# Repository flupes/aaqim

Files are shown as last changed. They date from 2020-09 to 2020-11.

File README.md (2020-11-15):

# aaqim = Arduino AQI Monitor

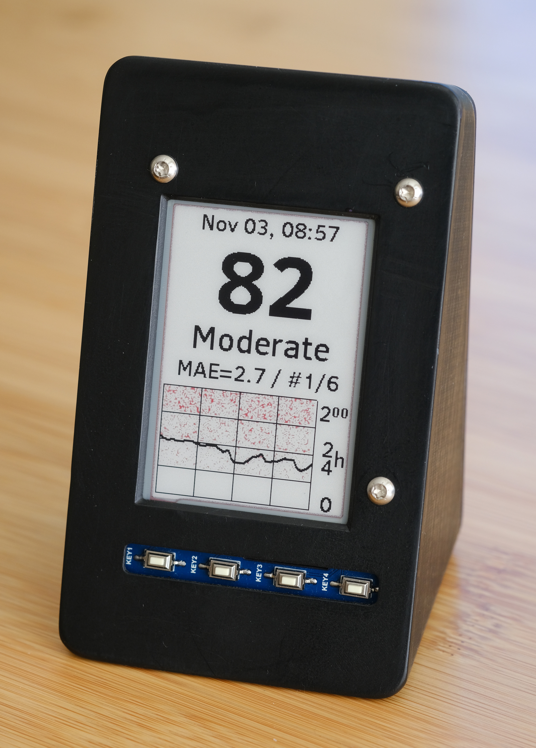
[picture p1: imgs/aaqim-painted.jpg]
AAQIM Monitor with Enclosure


Simple Air Quality Monitor using data collected from the **web** (no local sensor).

Based on an ESP8266 and E-paper display.

This is not a general, multi-purpose code base, but a quick hack for personal
use.

## Why

The air quality has been a real concern in the West from August 2020.
[Purple Air](https://www.purpleair.com/map) and
[Air Now](https://gispub.epa.gov/airnow/) maps are great tools to evaluate if
you can dare point your nose outside the confine of your shelter or not.
However, I wanted a solution that provides the current state of pollution in a
glimpse, without relying logging on a computer.

Ideally, you would setup your own sensor and create your DIY display to monitor
the pollution in real time. However, due to high demand, air quality sensors are
out of stock everywhere!

The next best option is then to use the data already available. There are more
than 15 Purple Air stations in a 500m diameter circle around my house, so it is
possible to get data localized enough to be relevant. The next requirement for
me was to create a low power solution: I would prefer to not contribute more to
the global warming just for my personal convinience. So a typical solution
relying on a Raspberry Pi single board computer is not considered here.

This project relies on micro-controller with WiFi capabilities to collect other
people sensor data. The display is based on a E-Paper panel that does not
consume current only when it needs to be updated. Since air quality is a slow
evolving parameter, the board and panel are simply stopped between updates,
leading to a very low power solution.

<p float="left">
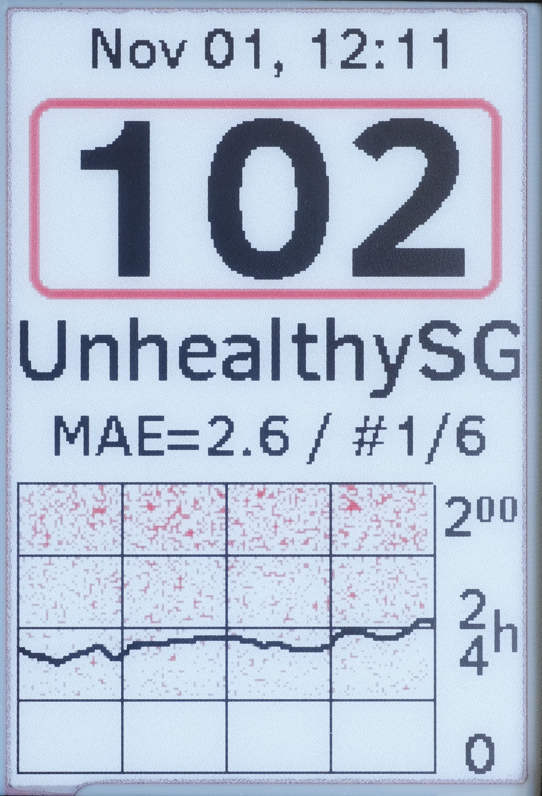
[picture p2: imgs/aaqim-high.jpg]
AAQIM Display Details
  
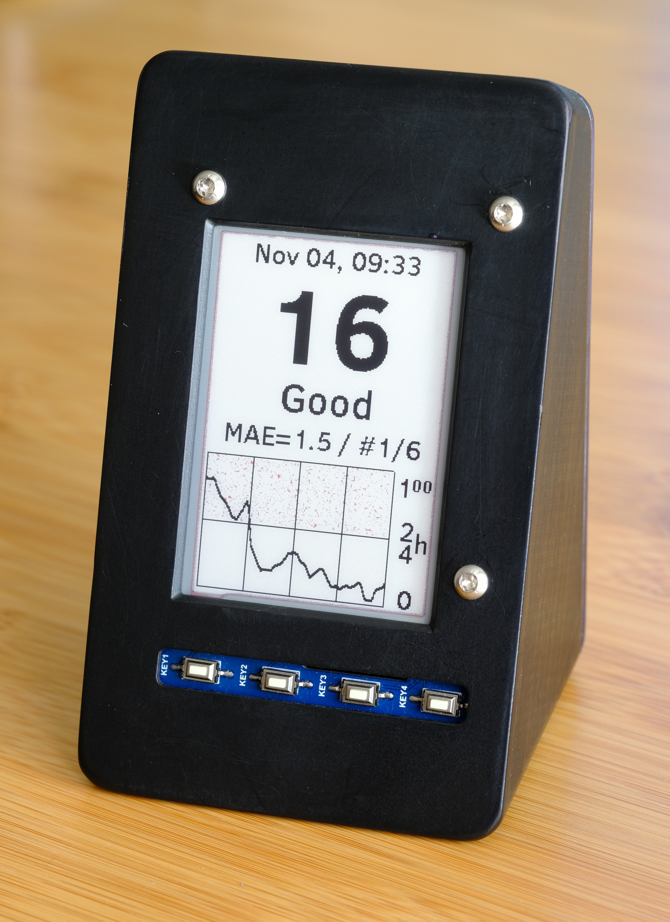
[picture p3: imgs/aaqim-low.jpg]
AAQIM Graph Display
  
</p>

## Details

  - [Some notes on the design](./design.md) (historical data and power consumption)
  - [Hardware related info](./hardware.md) (pinout, etc.)

The STL models for the enclosure are in the `./stls` directory.
The source Fusion-360 model is available with [this link](https://a360.co/31YtSna).
The enclosure holds the Huzzah in place without any screws.

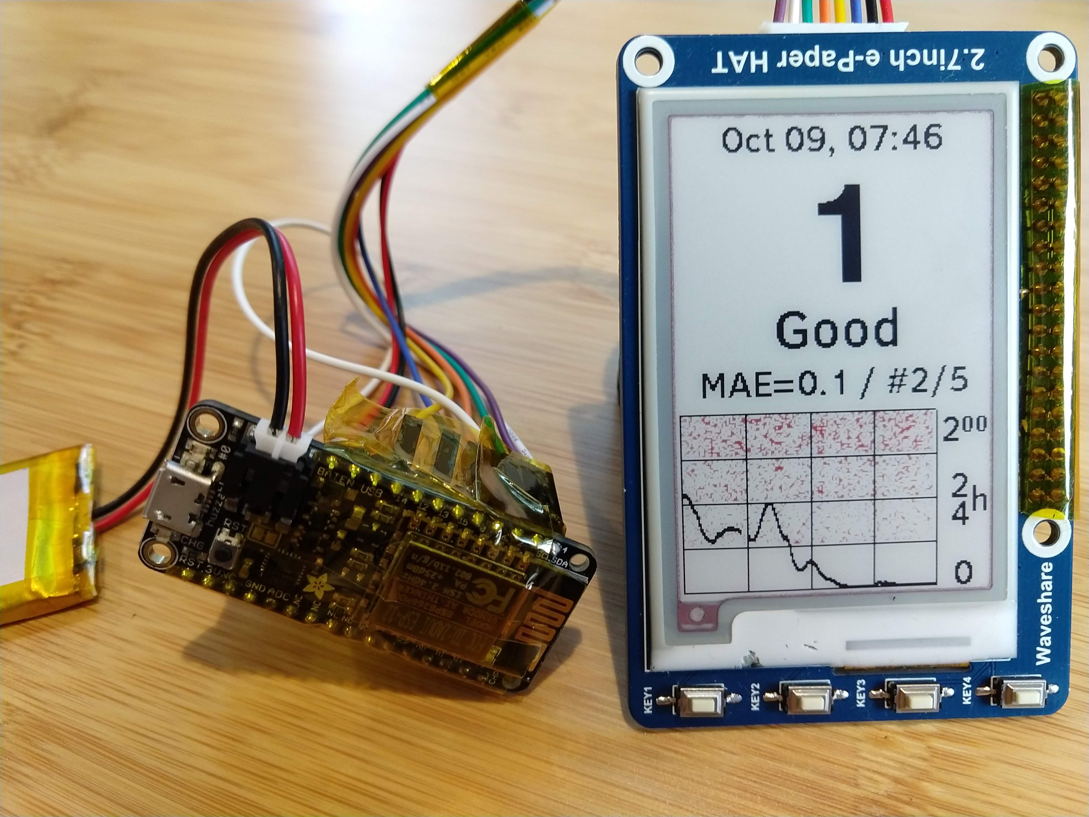
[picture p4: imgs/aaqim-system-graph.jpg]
AAQIM System


## Bill of Material

Not by design, just un-unsed parts from previous projects:
  - ESP8266 [Adafruit Huzzah](https://www.adafruit.com/product/2821)
    - This was before I selected SAMD21 boards instead. Still, the ESP8266 seems
      a interesting solution for super low cost projects.
  - [2.7in 3 colors E-paper Dislay](https://www.waveshare.com/product/displays/e-paper/epaper-2/2.7inch-e-paper-hat-b.htm)
    - I was initially attracted by the Black + Red capabilities of the panel,
    but refresh time was too slow (~20s) for ultra-low power projects like
    [DigiBaro](https://github.com/flupes/digibaro2/blob/master/README.md).
  - LiPo battery.

## How to build the software

The project is using
[PlatformIO](https://docs.platformio.org/en/latest/home/index.html). I develop
using Visual Studio Code (https://code.visualstudio.com/docs) which play nicely
with the PlatformIo extension.

Several of the unit test are also runnable on the native platform (Ubuntu 20.04
in my case). However, I configured the build to use a 32 bits architecture.
Since any modern computer will today be `amd64`, you will have to install the 32
bit compatibility packages:

    sudo apt install gcc-multilib g++-multilib

### Dependencies

Some dependencies are pulled using git submodules. Get them with:

    git submodule init
    git submodule update
    cd lib # symlink to avoid building the full waveshare source tree
    ln -s ../externals/ePaperDisplay/Arduino/epd2in7b epd2in7b

This includes the e-Paper driver from WaveShare and a fork of the great Adafruit GFX library.

Other "normal" dependencies are installed with PlatformIO:
  - ArduinoJson + StreamUtils from bblanchon

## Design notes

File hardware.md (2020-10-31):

# Some notes on the hardware

[Huzzah Pinout](https://learn.adafruit.com/adafruit-feather-huzzah-esp8266/pinouts)

[EPD Specs](https://www.waveshare.com/product/displays/e-paper/epaper-2/2.7inch-e-paper-hat-b.htm)

## Pin allocation

It turns out that the Huzzah has a very limited number of GPIO available: barely
enough to support this EPD!

Pins on the breakout but not available:
  - TX (#1)
  - RX (#3)

### EPD Control

| EPD # | EPD  Func. | Wire Color | Huzzah Pin |
|---:|:---:|:---:|---|
| 1 | VCC | Red | 3V |
| 2 | GND | Black | GND |
| 3 | DIN | Blue | MOSI (#13) |
| 4 | CLK | Yellow | SCK (#14) |
| 5 | CS | Orange | #0 (also Red LED)  |
| 6 | DC | Green | #2 (also Blue LED) |
| 7 | RST | White | #4 |
| 8 | BUSY | Purple | #5 |

So the blue LED will remain ON while from the begining of the display buffer transfer to the EPD until the board goes to sleep.

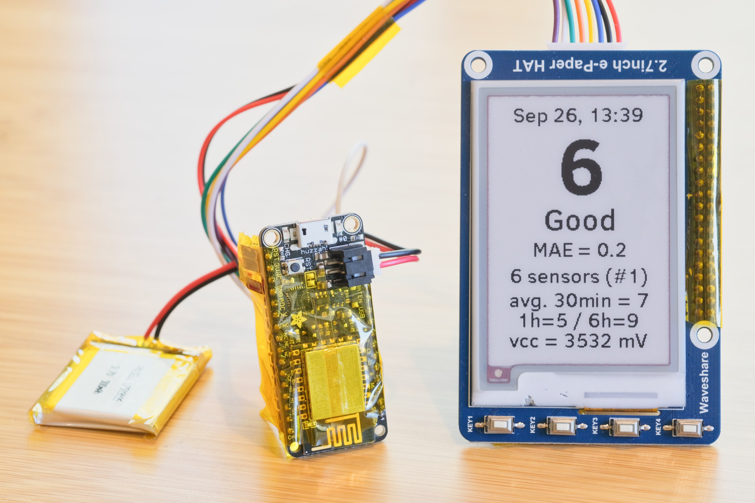
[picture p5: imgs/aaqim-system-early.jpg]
AAQIM System


### Other

Wake up from sleep:
  - #16 connected to RST

Battery Voltage:
  - Single Analog Input: ADC (1.0V max!)

Remains open:
  - #12 = MISO (not sure if available since we are using hardware SPI)
  - #15: with pullup resistor, used to detect boot-mode (yeah, one left!)

## PMS5003 Sensor

This project does not use a physical sensor, but we still need to understand the
Purple Air sensor properties to treat the data correctly. Purple Air sensors
basically combine *two* PMS5003 (and one BME280) in one package, allowing to
obtain more reliable measurements.

Purple Air does not declare the formulat to declare a 100% accuracy on a sensor
reading. From the
[PM5003 User Manual](https://cdn-shop.adafruit.com/product-files/3686/plantower-pms5003-manual_v2-3.pdf)
we some information about an individual sensor:

| Parameter | Values |
|---|---|
| Maximum Consistency | ±10% @ 100~500μg/m³ |
| Error | ±10μg/m³ @ 0~100μg/m³ |

So it seems that depending the particle concentration, we should use different
measure to declare that the two sensors are consistent.

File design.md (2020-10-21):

# Some notes on the design

## Collecting data

The data is retrieved as a JSON stream from a set of sensors using the Purple Air API.

Information about the Purple Air API is available in Google Doc accesible from:
https://www.purpleair.com/sensorlist

Some information about the fiels at:
https://www2.purpleair.com/community/faq#!hc-json-object-fields

A list of sensor IDs is declared in `lib/air_sensors/sensors.cpp` (by order of
priority).

To minimize the time the board is active, and not create additional load on the
PA server, the program retrieves data every 5 minutes.

## Data processing

A simple mean is computed from the real time pm 2.5 concentrations collected,
together with a mean absolute error (MAE) to provide a rough estimate of
the quality of the samples.

Then the concentration mean is converted to an Air Quality Index using the
non-linear mapping from the
[specification](https://www.airnow.gov/sites/default/files/2018-05/aqi-technical-assistance-document-may2016.pdf).

In addition, average over different time period are simply collected from the
primary sensors (the first sensor in the list that seems to have valid data).

## Graphing

Displaying a single instantaneous value is a no brainer. However, displaying a
graph of the last 24h trend opens a can of worms. Keeping the board powered at
all time and the data serie in RAM is not an option since the graph would be
lost at any power outage or user reset (during testing for example). So the
historical data needs to be persistant on the board if we want to avoid getting
it from another web service. Persistant historical data also allows to go in
deep sleep between AQI refresh.

### Data space required

Each AQI sample has a value between 0 and 500 max, so 9 bits are sufficient for
a data point But things become more complex if we
hope to build a monitor that last a few years and not wear out 

If we select January 1st, 2020 for our Epoch, we should outlast the board life
(and certainly the Purple Air API).

So we have: 22 bits (timestamp) + 9 bits (AQI) + 1 bit reserve = 4 bytes.

#### Absolute minimum required

Storage for 12h at 3' interval: 12 * 20 * 4 = 960 bytes total.

### EEPROM, Flash and wear leveling

The initial plan was to use the ESP8266 EEPROM to store the samples. The EEPROM
is 4KB only, which would cause some concern about too many rewrites.

Some projects like [EEPROM_rotate](https://github.com/xoseperez/eeprom_rotate)
*increase* the EEPROM size to limit wear leveling. It turns out it is possible
simply because the ESP8266 EEPROM is only emulated on top of flash memory!

ESP8266 also supports some minimal filesystem (SPIFFS or LittleFS), however this
is not suitable to store our samples because of the minimal size of the file,
and again this is totally overkill to simply store a data serie.

*It seems difficult to obtain the exact specification from the flash memory
inside a $3 micro-controller chip. However, several forums tend to indicate that
the flash on the ESP8266 could sustain 100'000 writes.*

The official documentation about the ESP8266 filesystem provides a
[super useful flash map](
https://arduino-esp8266.readthedocs.io/en/latest/filesystem.html).

The ESP8266 for the Huzzah comes with 4MB of flash total. 1MB is "reserved" by
default for SPIFFS. This is the flash area we will target to store our time
series. There is plenty of space to use large sample and still not worry about
wearing out the flash. However this required to implement a custom ring buffer
on top of the flash memory.

### Final historical data solution

Using the almost the 2MB of available flash allow to be more generous in term of
what we can store. The compacted data structure finally occupies 16 bytes and
the system declares a ring buffer of 40'960 samples. This is equivalent of 143
days of historical data that is stored on flash :-)

## Power consumption

Power consumption has been measured with two different approaches:
1) average draw when the board in on and updating the screen (~20s @ 80mA)
2) mini mAh meter over 60 samples

The result is ~0.5mAh per sample collected and graph refreshed. The power
consumption during deep sleep is negligeable compared to the display refresh.
This leads to less than 150mAh for a 24h period. This has been verified with the
tiny 500mAh (old) battery connected to the Huzzah that last more than 36h.

The project is not designed to be purely battery powered, however, you can at
anytime disconnect your the monitor from its USB charger and located it
somewhere else without worring about a power source for a while.

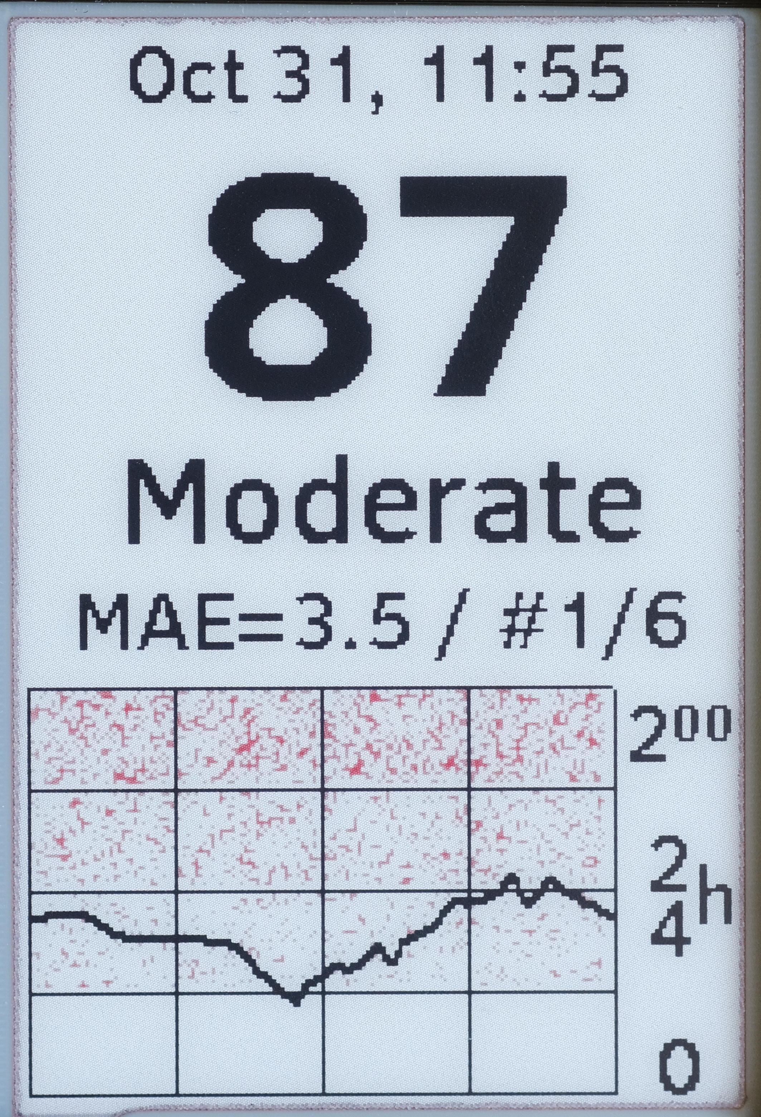
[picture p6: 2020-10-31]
imgs/aaqim-display.jpg

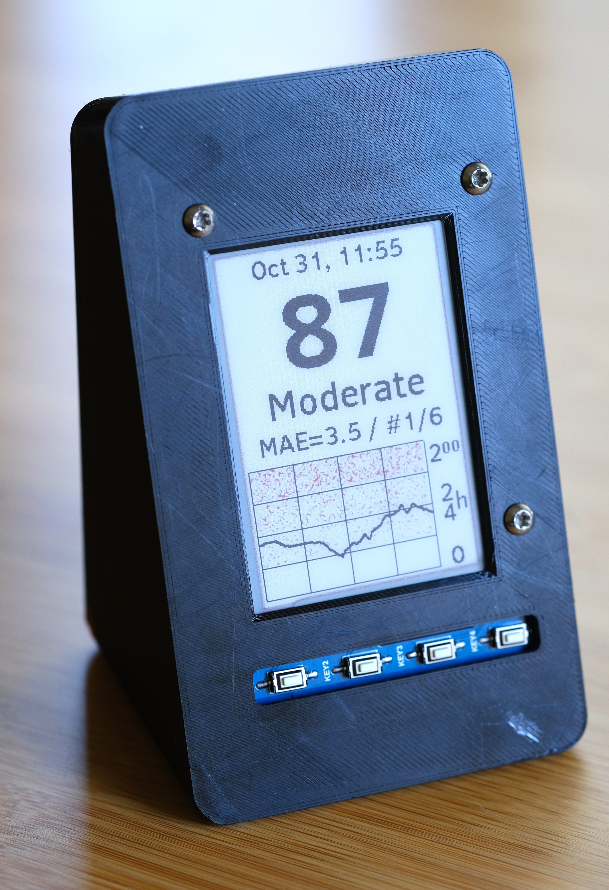
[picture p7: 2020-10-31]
imgs/aaqim-monitor.jpg

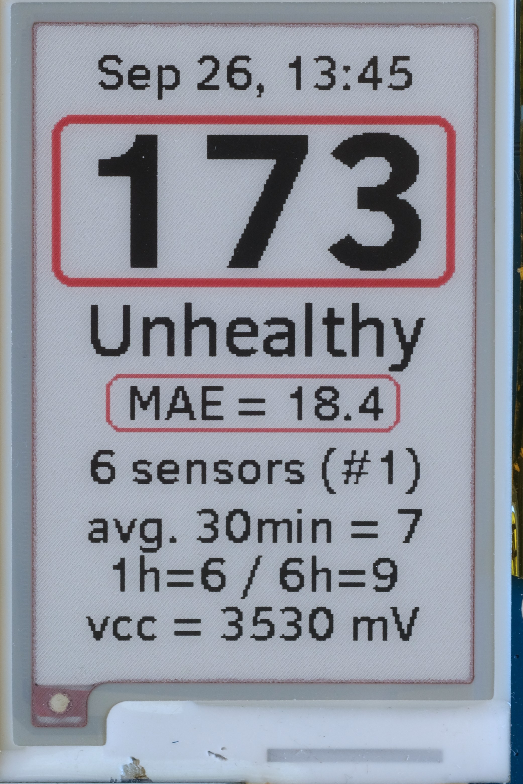
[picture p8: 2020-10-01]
imgs/aaqim-alarms.jpg

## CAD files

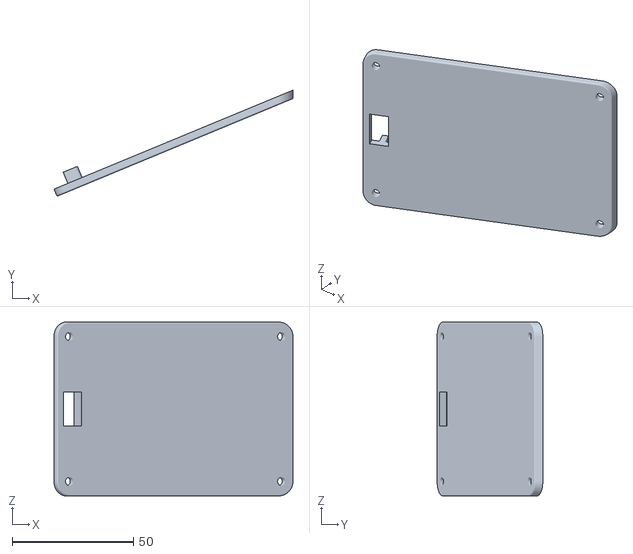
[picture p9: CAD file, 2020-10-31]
stls/aaqim_lid.stl
98.6 x 43.6 x 71.8

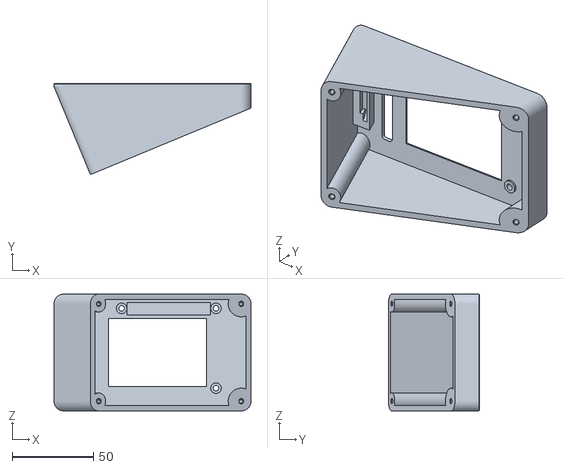
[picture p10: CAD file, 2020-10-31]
stls/aaqim_enclosure.stl
121.0 x 56.0 x 71.8

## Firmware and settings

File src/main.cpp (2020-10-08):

#if defined(ARDUINO)

#include <Adafruit_GFX.h>
#include <Arduino.h>
#include <ArduinoJson.h>
#include <ESP8266HTTPClient.h>
#include <ESP8266WiFi.h>
#include <time.h>

#include "Fonts/ClearSans-Bold-48pt7b.h"
#include "Fonts/ClearSans-Medium-12pt7b.h"
#include "Fonts/ClearSans-Medium-18pt7b.h"
#include "analyze.h"
#include "credentials.h"
#include "epd2in7b.h"
#include "graph_samples.h"
#include "sensors.h"

#define COLORED 1
#define UNCOLORED 0

Epd epd;
// This is ugly. TODO: encapsulate these 2 canvas in a proper class
GFXcanvas1 *canvas[2];

EspFlash gFlash;
FlashSamples<AirSampleData> gFlashSamples(gFlash, 0xA000);

// Use the AD converted of the ESP8266 to read the chip supply
// voltage (instean of the analog input pin)
ADC_MODE(ADC_VCC);

const time_t kTimeZoneOffsetSeconds = -7 * 3600;

enum class ColorBuffer : uint8_t { Black = 0, Red = 1 };

void CenterText(const GFXfont *font, const char *str, uint16_t line,
                ColorBuffer color = ColorBuffer::Black) {
  int16_t x, y;
  uint16_t w, h;
  uint8_t bufferId = static_cast<uint8_t>(color);
  canvas[bufferId]->setFont(font);
  canvas[bufferId]->getTextBounds(str, 0, 100, &x, &y, &w, &h);
  int16_t offset = 0;
  if (str[0] == '1') {
    offset = h / 8;
  }
  canvas[bufferId]->setCursor((EPD_WIDTH - w) / 2 - offset, line);
  canvas[bufferId]->print(str);
}

void setup() {
  Serial.begin(115200);
  Serial.setDebugOutput(true);
  Serial.println();

  Serial.print("Memory heap entering setup() = ");
  size_t startHeap = ESP.getFreeHeap();
  Serial.println(startHeap);
  Serial.print("Fragmentation = ");
  Serial.println(ESP.getHeapFragmentation());

  gFlashSamples.Begin();
  printf("nb of sectors in use : %d\n", gFlashSamples.SectorsInUse());
  printf("first addr of reserved : 0x%08X\n",
         gFlashSamples.FlashStorageStart());
  printf("end of reserved flash  : 0x%08X\n", gFlashSamples.FlashStorageEnd());
  printf("nominal number of samples : %d\n", gFlashSamples.NominalCapacity());
  printf("current number of samples stored : %d\n",
         gFlashSamples.NumberOfSamples());

  // Wiped flash in 4986 ms
  // nb of sectors in use : 160
  // last addr of reserved : 3801088
  // nominal number of samples : 40704
  // current number of samples stored : 0

  // UT flash start : 3801088

  Serial.println("Init e-Paper...");
  if (epd.Init() != 0) {
    Serial.println("e-Paper init failed");
    return;
  }
  epd.ClearFrame();

  Serial.print("Looking for wifi ");
  unsigned long start = millis();
  bool timeout = false;
  WiFi.begin(SSID, PASS);
  while (!timeout && WiFi.status() != WL_CONNECTED) {
    delay(500);
    Serial.print(".");
    if (millis() - start > 45 * 1000) {
      timeout = true;
    }
  }
  Serial.println();

  // seconds is first initialized to the latest sample on record
  // If a new sample if retrieve from the net, then seconds
  // will be updated.
  time_t seconds;
  {
    AirSampleData data;
    AirSample last;
    gFlashSamples.ReadSample(0, data);
    last.FromData(data);
    seconds = last.Seconds();
  }

  if (WiFi.status() == WL_CONNECTED) {
    Serial.println();
    Serial.println("WiFi Connected :-)");
    WiFiClient client;
    HTTPClient http;

    AirSensors sensors;
    for (size_t i = 0; i < sizeof(kSensorIds) / sizeof(size_t); i++) {
      sensors.AddSensor(kSensorIds[i]);
    }
    Serial.println("Update data");
    sensors.UpdateData(client, http);
    Serial.println("List of sensors");
    sensors.PrintAllData();

    // Disconnect
    http.end();

    Serial.print("Memory heap before Canvas = ");
    Serial.println(ESP.getFreeHeap());
    canvas[0] = new GFXcanvas1(EPD_WIDTH, EPD_HEIGHT);
    canvas[1] = new GFXcanvas1(EPD_WIDTH, EPD_HEIGHT);
    Serial.print("Memory heap after Canvas = ");
    Serial.println(ESP.getFreeHeap());

    for (uint8_t i = 0; i < 2; i++) {
      canvas[i]->fillScreen(UNCOLORED);
      canvas[i]->setTextColor(COLORED);
      canvas[i]->setTextSize(1);
      canvas[i]->setTextWrap(false);
    }

    AirSample sample;
    int32_t primaryIndex;
    size_t nbSamples = ComputeStats(sensors, sample, primaryIndex);
#if 0
    // Photo Op only :-)
    sample.Set(sample.Seconds(), 0.0, 98.1, 0.0, 0.0, 0, 0, sample.SamplesCount(), 18.4);
    //sample.Set(sample.Seconds(), 0.0, 1.4, 0.0, 0.0, 0, 0, sample.SamplesCount(), 0.2);
#endif

    if (nbSamples > 0) {
      // Store permanently sample to flash
      AirSampleData compacted;
      sample.ToData(compacted);
      gFlashSamples.StoreSample(compacted);

      seconds = sample.Seconds();
      time_t localSeconds = seconds + kTimeZoneOffsetSeconds;
      tm *local = gmtime(&localSeconds);
      char date[16];
      strftime(date, 16, "%b %d, %Y", local);
      char stamp[16];
      strftime(stamp, 16, "%H:%M:%S", local);
      Serial.print(date);
      Serial.print(" - ");
      Serial.println(stamp);
      char datetime[16];
      strftime(datetime, 16, "%b %d, %H:%M", local);

      CenterText(&ClearSans_Medium12pt7b, datetime, 18);

      int16_t aqi = sample.AqiPm_2_5();
      Serial.print("AQI = ");
      Serial.print(aqi);
      Serial.print(" --> ");
      Serial.println(AqiNames[static_cast<int>(sample.Level())]);
      if (aqi > 100) {
        canvas[1]->fillRoundRect(6, 29, EPD_WIDTH - 2 * 6, 70, 8, COLORED);
        canvas[1]->fillRoundRect(10, 33, EPD_WIDTH - 2 * 10, 62, 4, UNCOLORED);
      }
      String aqiValue(aqi);
      CenterText(&ClearSans_Bold48pt7b, aqiValue.c_str(), 90);

      String aqiName(AqiNames[static_cast<int>(sample.Level())]);
      CenterText(&ClearSans_Medium18pt7b, aqiName.c_str(), 126);

      char msg[16];
      float mae = sample.MaeValue();
      if (mae > 15.0) {
        canvas[1]->fillRoundRect(28, 134, EPD_WIDTH - 2 * 28, 24, 6, COLORED);
        canvas[1]->fillRoundRect(30, 136, EPD_WIDTH - 2 * 30, 20, 4, UNCOLORED);
      }
      sprintf(msg, "MAE=%.1f / #%d/%d", sample.MaeValue(), primaryIndex+1, sample.SamplesCount());
      CenterText(&ClearSans_Medium12pt7b, msg, 152);

#if 0
      sprintf(msg, "MAE = %.1f", sample.MaeValue());
      CenterText(&ClearSans_Medium12pt7b, msg, 152);

      sprintf(msg, "%d sensors (#%d)", sample.SamplesCount(), primaryIndex + 1);
      CenterText(&ClearSans_Medium12pt7b, msg, 184);

      SensorData data = sensors.Data(primaryIndex);
      int16_t value30m, value1h, value6h, value24h;
      AqiLevel level;
      pm25_to_aqi(data.averages[static_cast<int>(PmAvgIndexes::ThirtyMinutes)],
                  value30m, level);
      pm25_to_aqi(data.averages[static_cast<int>(PmAvgIndexes::OneHour)],
                  value1h, level);
      pm25_to_aqi(data.averages[static_cast<int>(PmAvgIndexes::SixHours)],
                  value6h, level);
      pm25_to_aqi(
          data.averages[static_cast<int>(PmAvgIndexes::TwentyFourHours)],
          value24h, level);
      sprintf(msg, "avg. 30min = %d", value30m);
      CenterText(&ClearSans_Medium12pt7b, msg, 208);

      sprintf(msg, "1h=%d / 6h=%d", value1h, value6h);
      CenterText(&ClearSans_Medium12pt7b, msg, 228);

      // sprintf(msg, "avg. 24h = %d", value24h);
      // CenterText(&ClearSans_Medium12pt7b, msg, 248);

      uint16_t vcc = ESP.getVcc();
      Serial.print("VCC = ");
      Serial.println(vcc);
      sprintf(msg, "vcc = %d mV", vcc);
      CenterText(&ClearSans_Medium12pt7b, msg, 248);
#endif

    } else {
      Serial.println("No valid air sample retrieved :-/");
      CenterText(&ClearSans_Medium18pt7b, "No Data :-/", 132);
    }

  } else {
    // not connected, too bad :-(
    Serial.println("Could not connected to WiFi :-(");
    CenterText(&ClearSans_Medium18pt7b, "No WiFi :-(", 132);
  }

  GraphSamples graph(10 * 60);
  graph.Fill(gFlashSamples, seconds, pm25_to_aqi_value);
  for (size_t i=0; i<graph.Length(); i+=14) {
    printf("sample #%d : %d\n", i, graph.Value(i));
  }
  graph.Draw(canvas[0], canvas[1]);

  epd.TransmitPartial(canvas[0]->getBuffer(), canvas[1]->getBuffer(), 0, 0,
                      EPD_WIDTH, EPD_HEIGHT);
  epd.DisplayFrame();

  Serial.println("Put display to sleep");
  epd.Sleep();
  delay(500);

  delete canvas[0];
  delete canvas[1];

  Serial.print("Memory heap before going to sleep = ");
  size_t sleepHeap = ESP.getFreeHeap();
  Serial.println(sleepHeap);
  Serial.print("Fragmentation = ");
  Serial.println(ESP.getHeapFragmentation());
  Serial.print("Memory potentially leaked = ");
  Serial.println(startHeap - sleepHeap);

  Serial.println("Now go to sleep for 5 minutes");
  ESP.deepSleep(5 * 60 * 1E6);
}

void loop() {}

#else
// Something trivial to avoid pio errors
int main(void) { return 0; }
#endif

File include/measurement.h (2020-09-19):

#ifndef AAQIM_MEASUREMENT_H
#define AAQIM_MEASUREMENT_H

#include <stdint.h>

#include "cfaqi.h"

static const uint32_t MEASUREMENT_SIZE = 16;

const uint32_t k2019epoch = 1546300800;  // Offset for compacted timestamps

const int16_t kTemperatureOffsetF = -100;
const uint32_t kPressureOffsetPa = 60000U;
const uint32_t kMaxRecordablePressurePa = 125500U;

const uint32_t kSecondsResolution = 60;

uint16_t pressure_mbar_to_short(float pressure_mbar) {
  uint16_t coded_pressure;
  if (pressure_mbar < (float)kPressureOffsetPa / 100.0) {
    coded_pressure = 0;
  } else if (pressure_mbar > (float)kMaxRecordablePressurePa / 100.0) {
    coded_pressure = (uint16_t)(kMaxRecordablePressurePa - kPressureOffsetPa);
  } else {
    coded_pressure = (uint16_t)(100.0 * pressure_mbar - kPressureOffsetPa);
  }
  return coded_pressure;
}

float short_to_mbar_pressure(uint16_t coded_pressure) {
  return (float)((uint32_t)(coded_pressure) + kPressureOffsetPa) / 100.0;
}

uint8_t temperature_f_to_byte(int16_t temperature_f) {
  uint8_t coded_temperature;
  if (temperature_f < kTemperatureOffsetF) {
    coded_temperature = 0;
  } else if (temperature_f > (0xFF + kTemperatureOffsetF)) {
    coded_temperature = 0xFF;
  } else {
    coded_temperature = temperature_f + kTemperatureOffsetF;
  }
  return coded_temperature;
}

int16_t byte_to_temperature_f(uint8_t coded_temperature) {
  return (int16_t)(coded_temperature)-kTemperatureOffsetF;
}

uint16_t cf_to_short(float concentration) {
  uint16_t coded_concentration;
  if (concentration < 0.0f) {
    coded_concentration = 0;
  } else if (concentration > 512.0f) {
    coded_concentration = 0xFFFF;
  } else {
    coded_concentration = (uint16_t)(concentration * 128.0f);
  }
  return coded_concentration;
}

float short_to_cf(uint16_t coded_concentration) {
  return (float)coded_concentration / 128.0f;
}

void unix_seconds_to_timestamp_22bits(uint32_t seconds, uint8_t ts24[]) {
  uint32_t timestamp32;
  if (seconds < k2019epoch) {
    timestamp32 = 0;
  } else {
    timestamp32 = (seconds - k2019epoch) / kSecondsResolution;
    timestamp32 &= 0x3FFFFF;  // forget bits of rank larger than 22!
  }
  ts24[0] = timestamp32 >> 16;
  ts24[1] = (0xFFFF & timestamp32) >> 8;
  ts24[2] = 0xFF & timestamp32;
}

void timestamp_22bits_to_unix_seconds(const uint8_t ts24[], uint32_t &seconds) {
  uint32_t timestamp32;
  timestamp32 = ((uint32_t)(ts24[0]) << 16) + ((uint16_t)(ts24[1]) << 8) + ts24[2];
  seconds = timestamp32 * kSecondsResolution + k2019epoch;
}

struct MeasurementData {
  uint8_t timestamp24[3];
  uint8_t reserved;
  uint16_t pm_1_0_short;
  uint16_t pm_2_5_short;
  uint16_t pm_10_0_short;
  uint16_t pressure_short;
  uint8_t temperature_byte;
  uint8_t humidity_byte;
  uint8_t quality_byte;
  uint8_t crc;
};

class Measurement {
 public:
  Measurement() { Set(k2019epoch, 0.0f, 0.0f, 0.0f, 1000.0f, 0, 0); }

  Measurement(uint32_t seconds, float pm_1_0, float pm_2_5, float pm_10,
              float pressure, int temperature, int humidity) {
    Set(seconds, pm_1_0, pm_2_5, pm_10, pressure, temperature, humidity);
  }

  Measurement(const MeasurementData &data) {
    timestamp_22bits_to_unix_seconds(data.timestamp24, seconds_);
    pm_1_0_cf_ = short_to_cf(data.pm_1_0_short);
    pm_2_5_cf_ = short_to_cf(data.pm_2_5_short);
    pm_10_0_cf_ = short_to_cf(data.pm_10_0_short);
    pressure_ = short_to_mbar_pressure(data.pressure_short);
    temperature_f_ = byte_to_temperature_f(data.temperature_byte);
    humidity_ = data.humidity_byte;
    pm25_to_aqi(pm_2_5_cf_, aqi_pm25_, aqi_level_);
  }

  void Set(uint32_t seconds, float pm_1_0, float pm_2_5, float pm_10,
           float pressure, int temperature, int humidity) {
    seconds_ = seconds;
    pm_1_0_cf_ = pm_1_0;
    pm_2_5_cf_ = pm_2_5;
    pm_10_0_cf_ = pm_10;
    pressure_ = pressure;
    temperature_f_ = temperature;
    if (humidity > 100) {
      humidity_ = 100;
    } else if (humidity < 0) {
      humidity = 0;
    } else {
      humidity_ = humidity;
    }
    pm25_to_aqi(pm_2_5_cf_, aqi_pm25_, aqi_level_);
  }

  void SetData(MeasurementData &data) {
    unix_seconds_to_timestamp_22bits(seconds_, data.timestamp24);
    data.pm_1_0_short = cf_to_short(pm_1_0_cf_);
    data.pm_2_5_short = cf_to_short(pm_2_5_cf_);
    data.pm_10_0_short = cf_to_short(pm_10_0_cf_);
    data.pressure_short = pressure_mbar_to_short(pressure_);
    data.temperature_byte = temperature_f_to_byte(temperature_f_);
    data.humidity_byte = humidity_;
    data.crc = 0;  // TOFIX !
  }

 protected:
  uint32_t seconds_;
  float pm_1_0_cf_;
  float pm_2_5_cf_;
  float pm_10_0_cf_;
  float pressure_;
  int16_t temperature_f_;
  int16_t aqi_pm25_;
  uint8_t humidity_;
  AqiLevel aqi_level_;
};

#endif

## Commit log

2020-09-17 added a sample of json data retrieved from PA
2020-09-17 compute the AQI from the sensors
2020-09-19 cleaner solution to avoid pio warnings
    [main.cpp]
2020-09-19 made the test runnable on the target board
2020-09-20 filter out lib directory for native build
2020-09-21 working prototype :-)
2020-09-21 corrected level to show red
    [main.cpp]
2020-09-22 added collection of PA stats for each sensor
2020-09-22 added an interesting sample that breaks the stats
2020-09-22 returns the primary sensor used
2020-09-24 switched to use MAE instead of NMEA
2020-09-24 added notes on the hardware setup and sensor
2020-09-24 use 10min average rather than real time, and display error differently
    [main.cpp]
2020-09-29 almost functional flash samples
2020-10-01 Inserted pic
2020-10-01 inserted links
2020-10-03 switched to non-templatized flash support
2020-10-04 added class to put samples in display buckets
2020-10-05 added a macro to print only in debug mode
2020-10-05 start to store samples on flash
2020-10-07 compute the limits on the bucket average
2020-10-21 updated doc and add power info
2020-10-31 added 3d files
    [aaqim_enclosure.stl, aaqim_lid.stl]
